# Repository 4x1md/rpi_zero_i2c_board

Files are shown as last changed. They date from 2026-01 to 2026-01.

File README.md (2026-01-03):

# I2C Peripherals Board for Raspberry Pi Zero

The board was developed for communicating some I2C peripherals connected to a Raspberry Pi Zero.

## Schematics

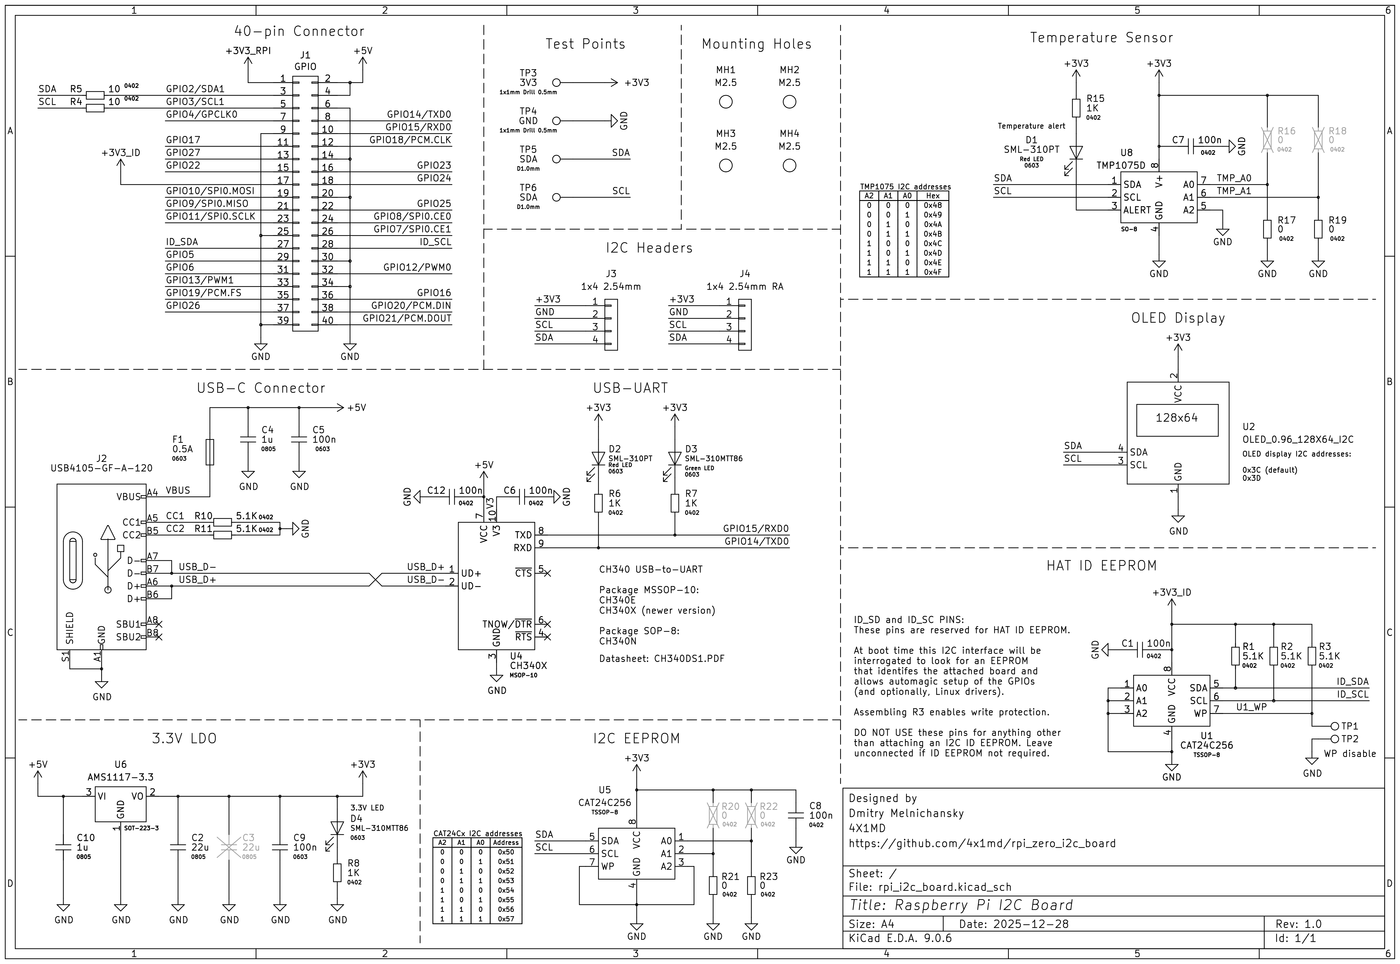
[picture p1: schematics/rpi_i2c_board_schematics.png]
Pi Zero I2C board schematics


## 3D Model

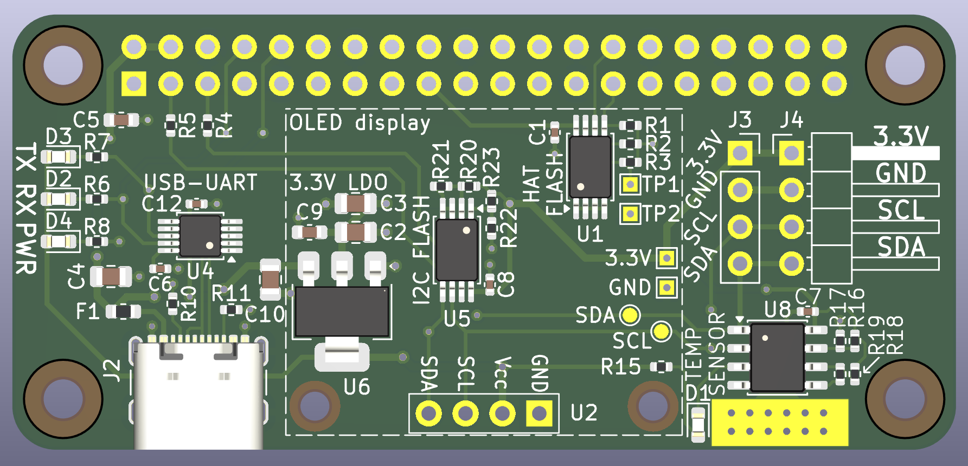
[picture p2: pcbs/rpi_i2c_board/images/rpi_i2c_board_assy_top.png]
Pi Zero I2C board 3D


## Questions? Suggestions?

You are more than welcome to contact me with any questions, suggestions or propositions regarding this project. Please drop an email to ```iosaaris =at= gmail dot com```.

## How to Support or Say Thanks

If you like this project, or found here some useful information and want to say thanks, or encourage me to do more, you can buy me a coffee!



"Buy Me A Coffee" (https://www.buymeacoffee.com/4x1md)

---

73 de 4X1MD

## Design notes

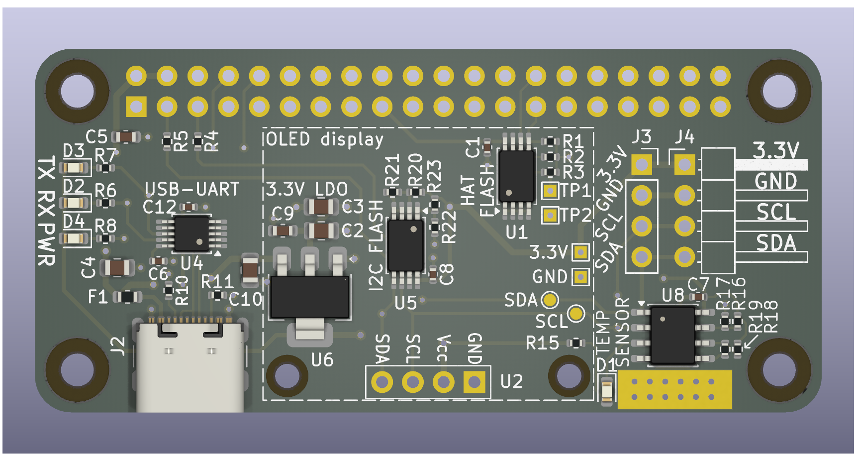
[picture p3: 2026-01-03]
pcbs/rpi_i2c_board/images/rpi_i2c_board_raytracing.png

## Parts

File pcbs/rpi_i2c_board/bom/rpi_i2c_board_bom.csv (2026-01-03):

Reference | Value | Footprint | Qty | FP | LSCS #
C1,C6,C7,C8,C12 | 100n | Capacitor_SMD:C_0402_1005Metric | 5 | 0402 | C1525
C2,C3 | 22u | Capacitor_SMD:C_0805_2012Metric | 2 | 0805 | C45783
C4,C10 | 1u | Capacitor_SMD:C_0805_2012Metric | 2 | 0805 | C28323
C5,C9 | 100n | Capacitor_SMD:C_0603_1608Metric | 2 | 0603 | C14663
D1,D2 | SML-310PT | LED_SMD:LED_0603_1608Metric | 2 | 0603 | C123009
D3,D4 | SML-310MTT86 | LED_SMD:LED_0603_1608Metric | 2 | 0603 | C122984
F1 | 0.5A | Fuse:Fuse_0603_1608Metric | 1 | 0603 | C7472539
J2 | USB4105-GF-A-120 | Connector_USB:USB_C_Receptacle_GCT_USB4105-xx-A_16P_TopMnt_Horizontal | 1 |  | C5184243
R1,R2,R3,R10,R11 | 5.1K | Resistor_SMD:R_0402_1005Metric | 5 | 0402 | C25905
R4,R5 | 10 | Resistor_SMD:R_0402_1005Metric | 2 | 0402 | C25077
R6,R7,R8,R15 | 1K | Resistor_SMD:R_0402_1005Metric | 4 | 0402 | C11702
R16,R17,R18,R19,R20,R21,R22,R23 | 0 | Resistor_SMD:R_0402_1005Metric | 8 | 0402 | C17168
U1,U5 | CAT24C256 | Package_SO:TSSOP-8_4.4x3mm_P0.65mm | 2 | TSSOP-8 | C146734
U4 | CH340X | Package_SO:MSOP-10_3x3mm_P0.5mm | 1 | MSOP-10 | C3035748
U6 | AMS1117-3.3 | Package_TO_SOT_SMD:SOT-223-3_TabPin2 | 1 | SOT-223-3 | C6186
U8 | TMP1075D | Package_SO:SO-8_3.9x4.9mm_P1.27mm | 1 | SO-8 | C2878381

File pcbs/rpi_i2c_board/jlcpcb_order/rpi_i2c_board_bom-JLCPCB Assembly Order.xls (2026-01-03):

JLCPCB BOM Tool - BOM Matching
BOM name：rpi_i2c_board_bom-JLCPCB Assembly Order.xlsx |  |  | Download Time：2025-12-28 21:13:16 |  |  |  | * Our matching results are updated in real-time, but stock and prices may change. If it's been over 24 hours, please re-match before placing your order.
PCB Assembled Qty：5 |  |  | Est. Total Price：18.3235
Your BOM |  |  |  |  | Matched Parts |  |  |  |  |  |  | Order Information
Top Designator | Bottom Designator | Comment | Footprint | JLCPCB Part # | Matches | Part # | Manufacturer | Footprint | Description | Category | Warning | JLCPCB Part # | Product link | Lib Type | Qty | Source | Total Price ($)
C1,C6,C7,C8,C12 |  | 100n | Capacitor_SMD:C_0402_1005Metric |  | Select by System | CL05B104KO5NNNC | Samsung Electro-Mechanics | 0402 | 100nF 16V X7R ±10% 0402 Multilayer Ceramic Capacitors MLCC - SMD/SMT ROHS | Multilayer Ceramic Capacitors MLCC - SMD/SMT |  | C1525 | https://jlcpcb.com/partdetail/1877-CL05B104KO5NNNC/C1525 | Basic | 25 | 25 JLCPCB | 0.03
C2,C3 |  | 22u | Capacitor_SMD:C_0805_2012Metric |  | Select by System | CL21A226MAQNNNE | Samsung Electro-Mechanics | 0805 | 22uF 25V X5R ±20% 0805 Multilayer Ceramic Capacitors MLCC - SMD/SMT ROHS | Multilayer Ceramic Capacitors MLCC - SMD/SMT |  | C45783 | https://jlcpcb.com/partdetail/46786-CL21A226MAQNNNE/C45783 | Basic | 10 | 10 JLCPCB | 0.232
C4,C10 |  | 1u | Capacitor_SMD:C_0805_2012Metric |  | Select by System | CL21B105KBFNNNE | Samsung Electro-Mechanics | 0805 | 1uF 50V X7R ±10% 0805 Multilayer Ceramic Capacitors MLCC - SMD/SMT ROHS | Multilayer Ceramic Capacitors MLCC - SMD/SMT |  | C28323 | https://jlcpcb.com/partdetail/29074-CL21B105KBFNNNE/C28323 | Basic | 10 | 10 JLCPCB | 0.091
C5,C9 |  | 100n | Capacitor_SMD:C_0603_1608Metric |  | Select by System | CC0603KRX7R9BB104 | YAGEO | 0603 | 100nF 50V X7R ±10% 0603 Multilayer Ceramic Capacitors MLCC - SMD/SMT ROHS | Multilayer Ceramic Capacitors MLCC - SMD/SMT |  | C14663 | https://jlcpcb.com/partdetail/YAGEO-CC0603KRX7R9BB104/C14663 | Basic | 10 | 10 JLCPCB | 0.024
D1,D2 |  | SML-310PT | LED_SMD:LED_0603_1608Metric |  | Select by System | SML-310VTT86 | ROHM Semicon | 0603 | 20mA 2V 4mcd 650nm 650nm Red Water Clear 0603 LED Indication - Discrete ROHS | LED Indication - Discrete |  | C123009 | https://jlcpcb.com/partdetail/ROHMSemicon-SML310VTT86/C123009 | Extended | 12 | 12 JLCPCB | 0.8556
D3,D4 |  | SML-310MTT86 | LED_SMD:LED_0603_1608Metric |  | Select by System | SML-310MTT86 | ROHM Semicon | 0603 | 16mcd 2.2V 20mA 570nm 570nm Green Water Clear 0603 LED Indication - Discrete ROHS | LED Indication - Discrete |  | C122984 | https://jlcpcb.com/partdetail/ROHMSemicon-SML310MTT86/C122984 | Extended | 14 | 14 JLCPCB | 1.19
F1 |  | 0.5A | Fuse:Fuse_0603_1608Metric |  | Select by System | 0603L050/16AR | LUTE | 0603 | -40℃~+85℃ 1.05mm 1.15mm 1.85mm 100ms 100mΩ 16V 1A 40A 500mA 500mW 800mΩ 0603 Resettable Fuses ROHS | Resettable Fuses |  | C7472539 | https://jlcpcb.com/partdetail/LUTE-0603L05016AR/C7472539 | Extended | 9 | 9 JLCPCB | 0.4959
J2 |  | USB4105-GF-A-120 | Connector_USB:USB_C_Receptacle_GCT_USB4105-xx-A_16P_TopMnt_Horizontal |  | Select by System | USB4105-GF-A-120 | Global Connector Technology | SMD | -40℃~+85℃ 1 16P 48V 5A Black Female Type-C USB2.0 SMD USB Connectors ROHS | USB Connectors |  | C5184243 | https://jlcpcb.com/partdetail/5849584-USB4105_GF_A120/C5184243 | Extended | 5 | 5 JLCPCB | 5.661
R1,R2,R3,R10,R11 |  | 5.1K | Resistor_SMD:R_0402_1005Metric |  | Select by System | 0402WGF5101TCE | UNI-ROYAL(Uniroyal Elec) | 0402 | -55℃~+155℃ 5.1kΩ 50V 62.5mW Thick Film Resistor ±1% ±100ppm/℃ 0402 Chip Resistor - Surface Mount ROHS | Chip Resistor - Surface Mount |  | C25905 | https://jlcpcb.com/partdetail/26648-0402WGF5101TCE/C25905 | Basic | 25 | 25 JLCPCB | 0.0125
R4,R5 |  | 10 | Resistor_SMD:R_0402_1005Metric |  | Select by System | 0402WGF100JTCE | UNI-ROYAL(Uniroyal Elec) | 0402 | -55℃~+155℃ 10Ω 50V 62.5mW Thick Film Resistor ±1% ±200ppm/℃ 0402 Chip Resistor - Surface Mount ROHS | Chip Resistor - Surface Mount |  | C25077 | https://jlcpcb.com/partdetail/25820-0402WGF100JTCE/C25077 | Basic | 10 | 10 JLCPCB | 0.006
R6,R7,R8,R15 |  | 1K | Resistor_SMD:R_0402_1005Metric |  | Select by System | 0402WGF1001TCE | UNI-ROYAL(Uniroyal Elec) | 0402 | -55℃~+155℃ 1kΩ 50V 62.5mW Thick Film Resistor ±1% ±100ppm/℃ 0402 Chip Resistor - Surface Mount ROHS | Chip Resistor - Surface Mount |  | C11702 | https://jlcpcb.com/partdetail/12256-0402WGF1001TCE/C11702 | Basic | 20 | 20 JLCPCB | 0.012
R16,R17,R18,R19,R20,R21,R22,R23 |  | 0 | Resistor_SMD:R_0402_1005Metric |  | Select by System | 0402WGF0000TCE | UNI-ROYAL(Uniroyal Elec) | 0402 | -55℃~+155℃ 0Ω 50V 62.5mW Thick Film Resistor ±1% ±800ppm/℃ 0402 Chip Resistor - Surface Mount ROHS | Chip Resistor - Surface Mount |  | C17168 | https://jlcpcb.com/partdetail/17853-0402WGF0000TCE/C17168 | Basic | 40 | 40 JLCPCB | 0.02
U1,U5 |  | CAT24C256 | Package_SO:TSSOP-8_4.4x3mm_P0.65mm |  | Select by System | CAT24C256YI-GT3 | onsemi | TSSOP-8 | -40℃~+85℃ 1,000,000 cycles 1.8V~5.5V 100 Years 1MHz 256Kbit 5ms I2C TSSOP-8 EEPROM ROHS | EEPROM |  | C146734 | https://jlcpcb.com/partdetail/onsemi-CAT24C256YIGT3/C146734 | Extended | 10 | 10 JLCPCB | 3.987
U4 |  | CH340X | Package_SO:MSOP-10_3x3mm_P0.5mm |  | Select by System | CH340X | WCH(Jiangsu Qin Heng) | MSOP-10 | -20℃~+70℃ 2Mbps 3.3V USB 2.0 USB to serial MSOP-10 USB Converters ROHS | USB Converters |  | C3035748 | https://jlcpcb.com/partdetail/WCH_Jiangsu_Qin_Heng-CH340X/C3035748 | Extended | 5 | 5 JLCPCB | 3.097
U6 |  | AMS1117-3.3 | Package_TO_SOT_SMD:SOT-223-3_TabPin2 |  | Select by System | AMS1117-3.3 | Advanced Monolithic Systems | SOT-223 | -40℃~+125℃ 0.003%Vout 1 1.1V@(800mA) 16V 1A 3.3V 5mA 72dB@(120Hz) Fixed Over Current Protection Positive SOT-223 Voltage Regulators - Linear, Low Drop Out (LDO) Regulators ROHS | Voltage Regulators - Linear, Low Drop Out (LDO) Regulators |  | C6186 | https://jlcpcb.com/partdetail/Advanced_MonolithicSystems-AMS1117_33/C6186 | Basic | 5 | 5 JLCPCB | 0.806
U8 |  | TMP1075D | Package_SO:SO-8_3.9x4.9mm_P1.27mm |  | Select by System | TMP1075DR | Texas Instruments | SOIC-8 | -55℃~+125℃ 1.7V~5.5V 12bit 3.5uA 7ms I2C ±1℃ SOIC-8 Temperature Sensors ROHS | Temperature Sensors |  | C2878381 | https://jlcpcb.com/partdetail/TexasInstruments-TMP1075DR/C2878381 | Extended | 5 | 5 JLCPCB | 1.8035

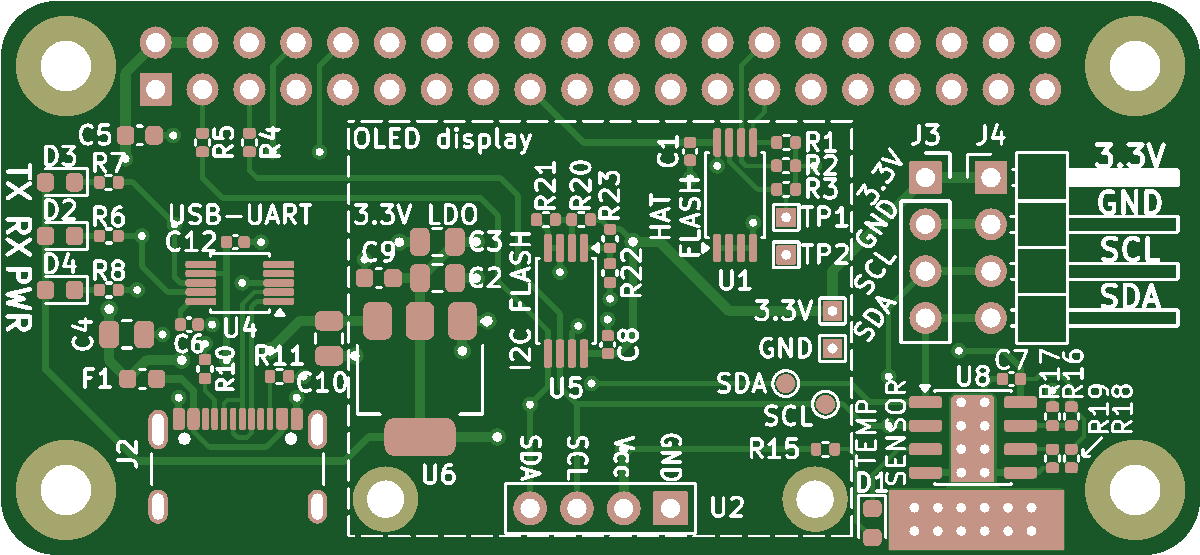
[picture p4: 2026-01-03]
pcbs/rpi_i2c_board/jlcpcb_order/rpi_i2c_board_jlcpcb_top.png

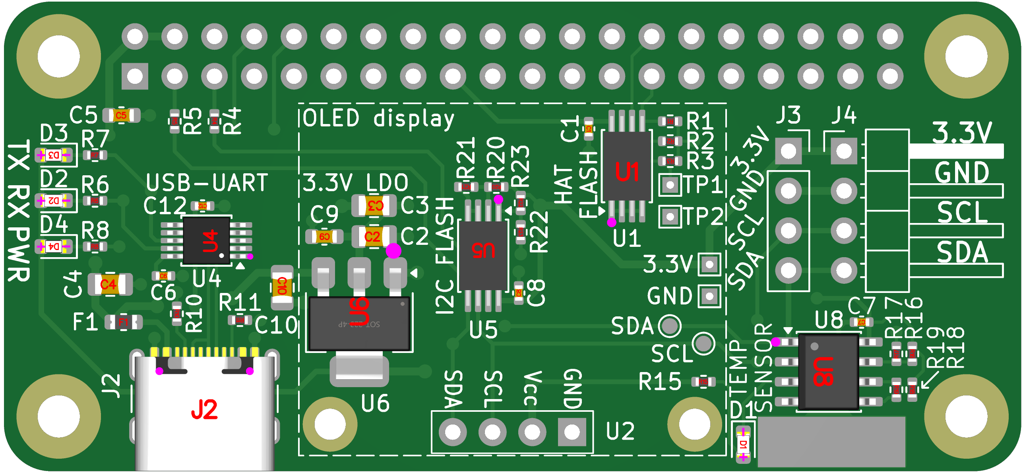
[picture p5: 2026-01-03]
pcbs/rpi_i2c_board/jlcpcb_order/rpi_i2c_board_jlcpcb_placement.png

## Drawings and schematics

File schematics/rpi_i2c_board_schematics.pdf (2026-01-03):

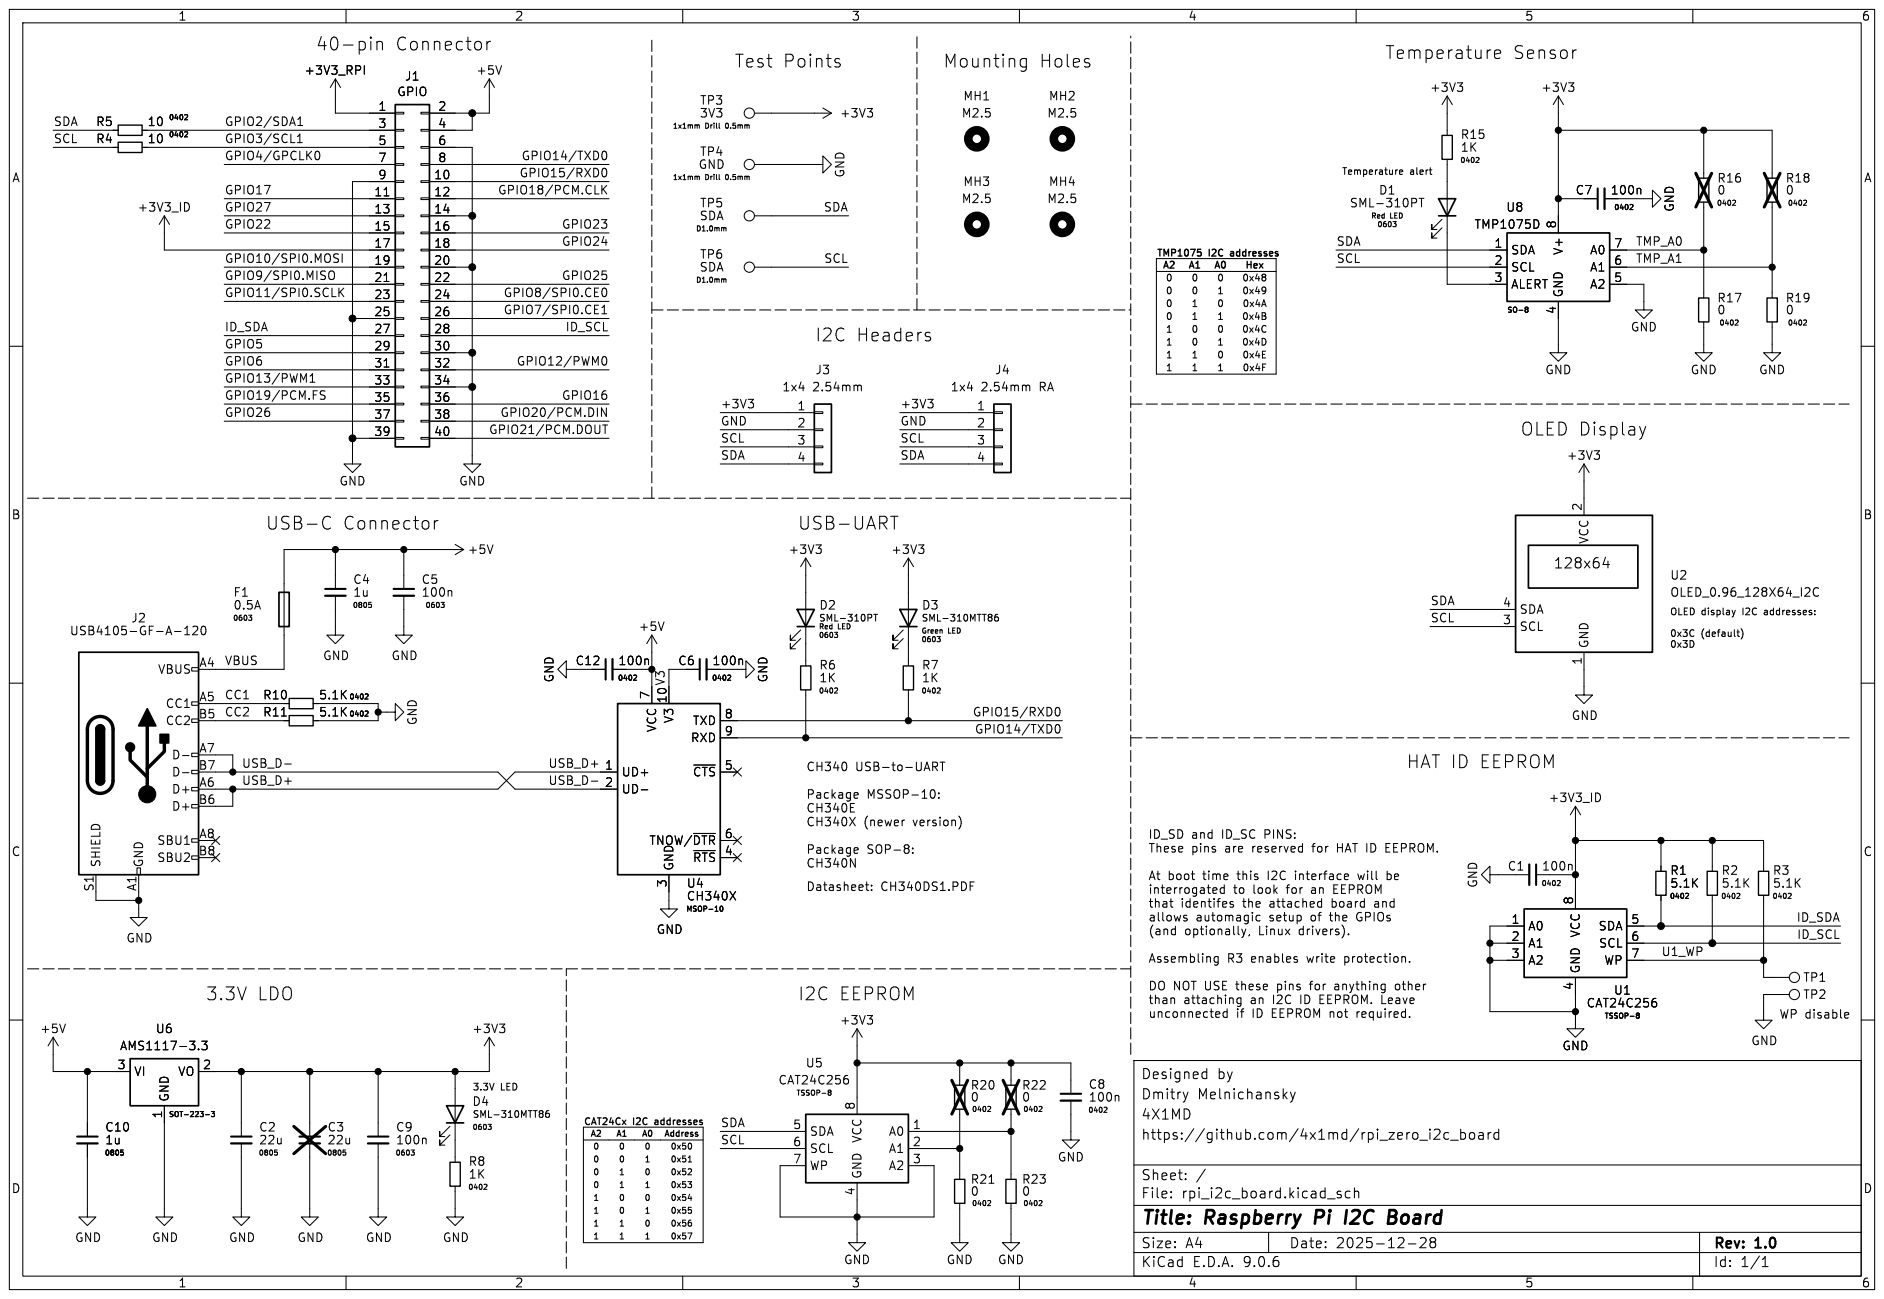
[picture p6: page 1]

+3V3 GPIO18/PCM.CLK GPIO15/RXD0 GPIO6 GPIO5 GPIO19/PCM.FS GPIO26 GPIO13/PWM1 GPIO9/SPI0.MISO

3 TXD 8 RXD 9 ~{CTS}5 TNOW/~{DTR}6 ~{RTS}4 U4 CH340X

3 TXD 8 RXD 9 ~{CTS}5 TNOW/~{DTR}6 ~{RTS}4

Package MSSOP-10: CH340E CH340X (newer version)

File: rpi_i2c_board.kicad_sch Sheet: / https://github.com/4x1md/rpi_zero_i2c_board

Id: 1/1 Title: Raspberry Pi I2C Board

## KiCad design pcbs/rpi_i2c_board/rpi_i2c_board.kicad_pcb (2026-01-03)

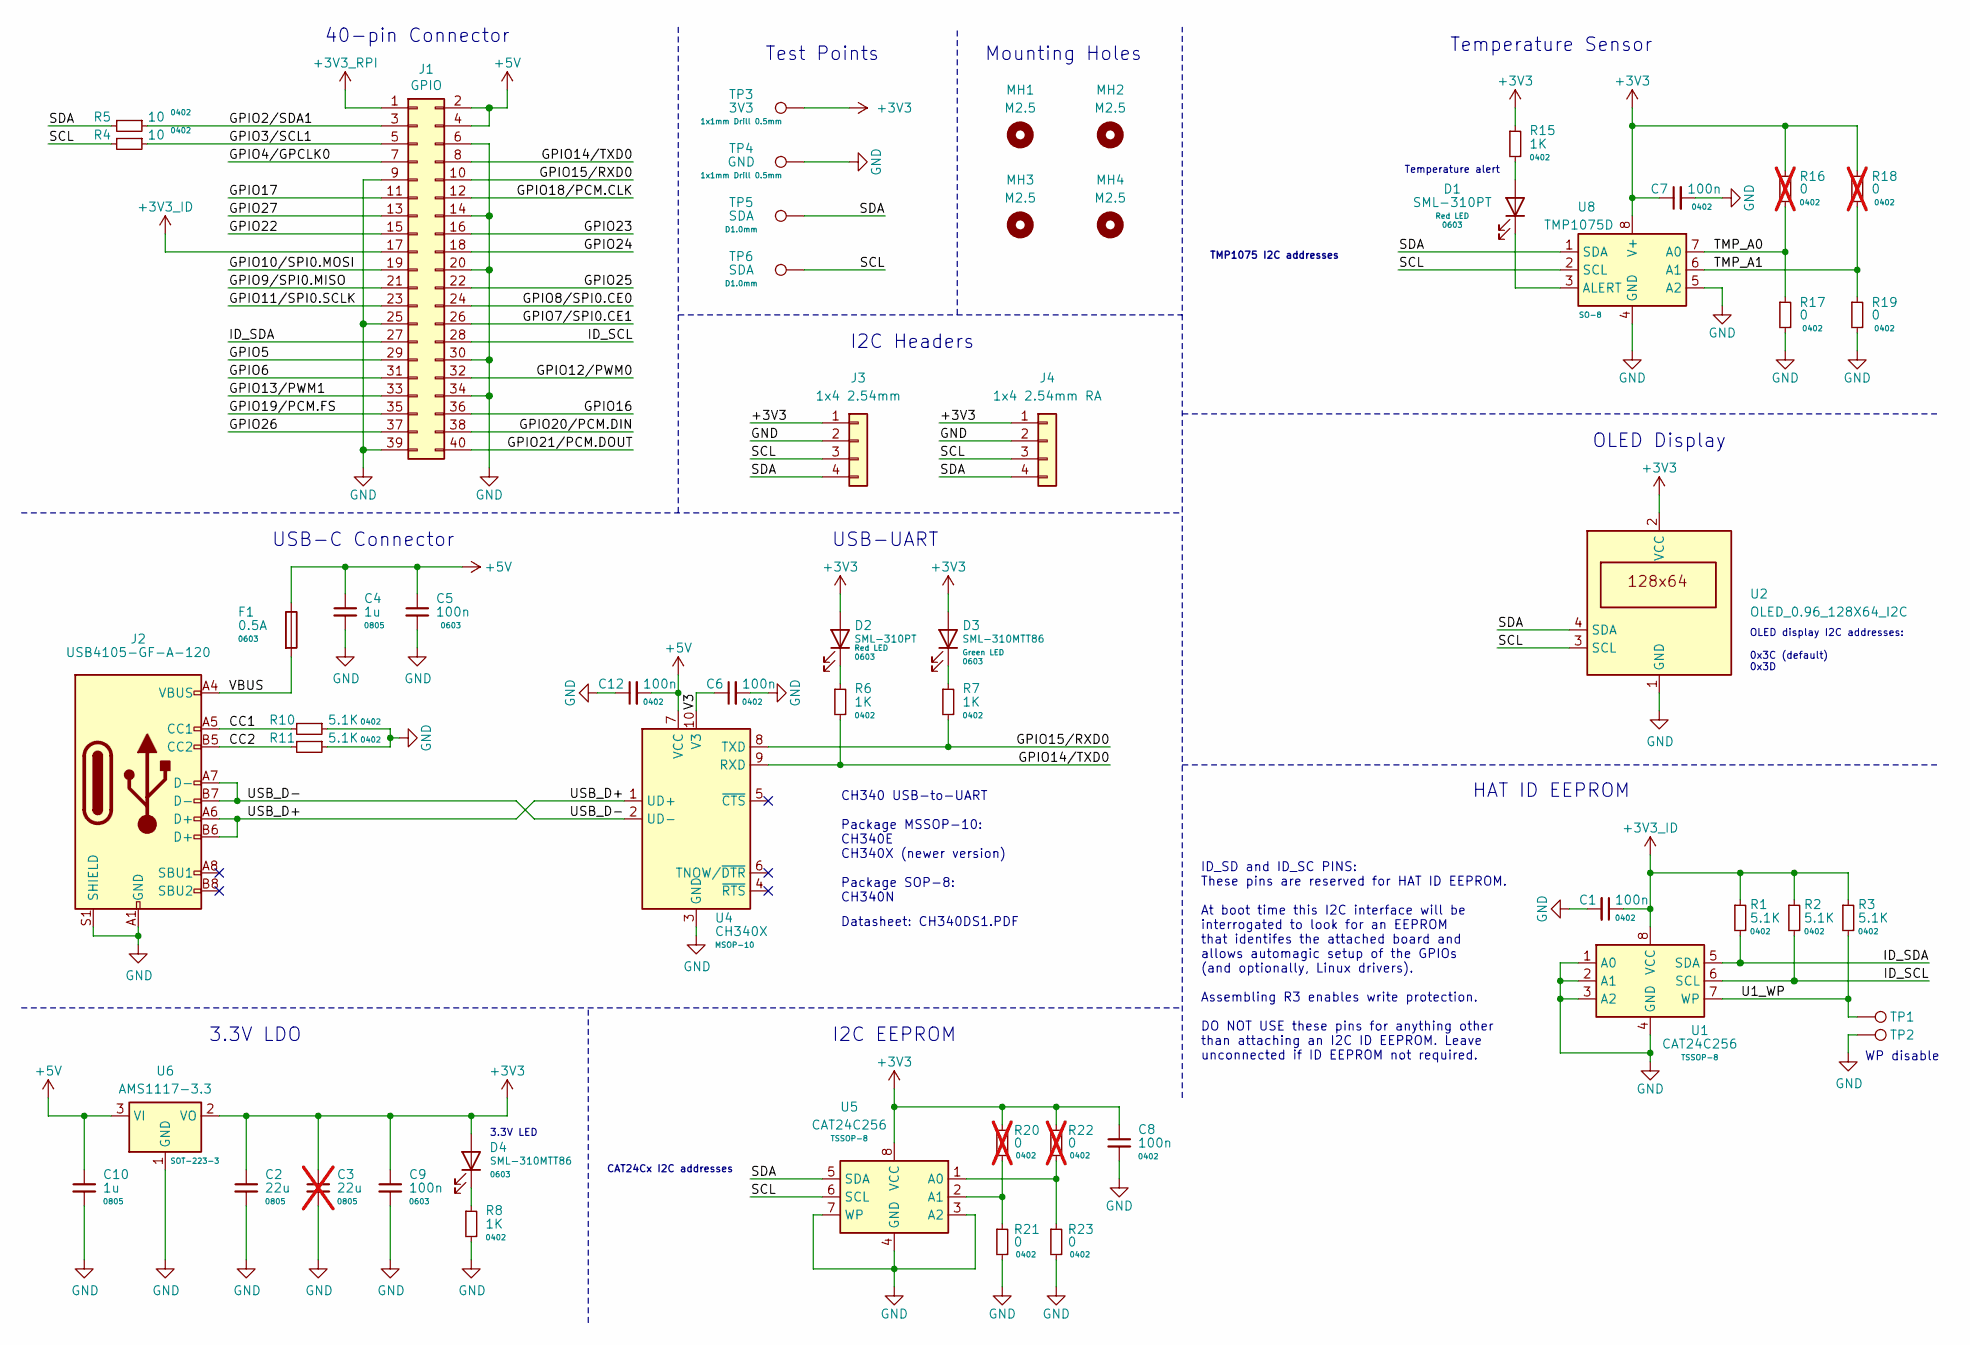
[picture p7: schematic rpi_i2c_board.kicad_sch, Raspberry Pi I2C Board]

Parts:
C1, C6, C7, C8, C12: 100n; C_0402_1005Metric
C2: 22u; C_0805_2012Metric
C3: 22u; C_0805_2012Metric; not fitted
C4, C10: 1u; C_0805_2012Metric
C5, C9: 100n; C_0603_1608Metric
D1, D2: SML-310PT; LED_0603_1608Metric
D3, D4: SML-310MTT86; LED_0603_1608Metric
F1: 0.5A; Fuse_0603_1608Metric
J1: GPIO; PinSocket_2x20_P2.54mm_Vertical
J2: USB4105-GF-A-120; USB_C_Receptacle_GCT_USB4105-xx-A_16P_TopMnt_Horizontal
J3: 1x4 2.54mm; PinSocket_1x04_P2.54mm_Vertical
J4: 1x4 2.54mm RA; PinHeader_1x04_P2.54mm_Horizontal
MH1, MH2, MH3, MH4: M2.5; MountingHole_2.7mm_M2.5_SolderMaskOpening
R1, R2, R3, R10, R11: 5.1K; R_0402_1005Metric
R4, R5: 10; R_0402_1005Metric
R6, R7, R8, R15: 1K; R_0402_1005Metric
R16, R18, R20, R22: 0; R_0402_1005Metric; not fitted
R17, R19, R21, R23: 0; R_0402_1005Metric
TP1: ID SDA; TestPoint_THTPad_1.0x1.0mm_Drill0.5mm
TP2: ID SCL; TestPoint_THTPad_1.0x1.0mm_Drill0.5mm
TP3: 3V3; TestPoint_THTPad_1.0x1.0mm_Drill0.5mm
TP4: GND; TestPoint_THTPad_1.0x1.0mm_Drill0.5mm
TP5, TP6: SDA; TestPoint_Pad_D1.0mm
U1, U5: CAT24C256; TSSOP-8_4.4x3mm_P0.65mm
U2: OLED_0.96_128X64_I2C; OLED_0.96_128X64_I2C_2MH
U4: CH340X; MSOP-10_3x3mm_P0.5mm
U6: AMS1117-3.3; SOT-223-3_TabPin2
U8: TMP1075D; SO-8_3.9x4.9mm_P1.27mm

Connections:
+3V3: C2.1, C3.1, C7.1, C8.1, C9.1, D2.2 (A), D3.2 (A), D4.2 (A), J3.1, J4.1, R15.1, R16.1, R18.1, R20.1, R22.1, TP3.1, U2.2 (VCC), U5.8 (VCC), U6.2 (VO), U8.8 (V+)
+3V3_ID: C1.1, J1.17, R1.1, R2.1, R3.1, U1.8 (VCC)
+3V3_RPI: J1.1
+5V: C4.1, C5.1, C10.1, C12.2, F1.1, J1.2, J1.4, U4.7 (VCC), U6.3 (VI)
/CC1: J2.A5 (CC1), R10.2
/CC2: J2.B5 (CC2), R11.2
/GPIO2/SDA1: J1.3, R5.1
/GPIO3/SCL1: J1.5, R4.1
/GPIO4/GPCLK0: J1.7
/GPIO5: J1.29
/GPIO6: J1.31
/GPIO7/SPI0.CE1: J1.26
/GPIO8/SPI0.CE0: J1.24
/GPIO9/SPI0.MISO: J1.21
/GPIO10/SPI0.MOSI: J1.19
/GPIO11/SPI0.SCLK: J1.23
/GPIO12/PWM0: J1.32
/GPIO13/PWM1: J1.33
/GPIO14/TXD0: J1.8, R6.2, U4.9 (RXD)
/GPIO15/RXD0: J1.10, R7.2, U4.8 (TXD)
/GPIO16: J1.36
/GPIO17: J1.11
/GPIO18/PCM.CLK: J1.12
/GPIO19/PCM.FS: J1.35
/GPIO20/PCM.DIN: J1.38
/GPIO21/PCM.DOUT: J1.40
/GPIO22: J1.15
/GPIO23: J1.16
/GPIO24: J1.18
/GPIO25: J1.22
/GPIO26: J1.37
/GPIO27: J1.13
/ID_SCL: J1.28, R2.2, U1.6 (SCL)
/ID_SDA: J1.27, R1.2, U1.5 (SDA)
/SCL: J3.3, J4.3, R4.2, TP6.1, U2.3 (SCL), U5.6 (SCL), U8.2 (SCL)
/SDA: J3.4, J4.4, R5.2, TP5.1, U2.4 (SDA), U5.5 (SDA), U8.1 (SDA)
/TMP_A0: R16.2, R17.1, U8.7 (A0)
/TMP_A1: R18.2, R19.1, U8.6 (A1)
/U1_WP: R3.2, TP1.1, U1.7 (WP)
/USB_D+: J2.A6 (D+), J2.B6 (D+), U4.1 (UD+)
/USB_D-: J2.A7 (D-), J2.B7 (D-), U4.2 (UD-)
/V3: C6.1, U4.10 (V3)
/VBUS: F1.2, J2.A4 (VBUS), J2.A9 (VBUS), J2.B4 (VBUS), J2.B9 (VBUS)
GND: C1.2, C2.2, C3.2, C4.2, C5.2, C6.2, C7.2, C8.2, C9.2, C10.2, C12.1, J1.6, J1.9, J1.14, J1.20, J1.25, J1.30, J1.34, J1.39, J2.A1 (GND), J2.A12 (GND), J2.B1 (GND), J2.B12 (GND), J2.S1 (SHIELD), J3.2, J4.2, R8.2, R10.1, R11.1, R17.2, R19.2, R21.2, R23.2, TP2.1, TP4.1, U1.1 (A0), U1.2 (A1), U1.3 (A2), U1.4 (GND), U2.1 (GND), U4.3 (GND), U5.3 (A2), U5.4 (GND), U5.7 (WP), U6.1 (GND), U8.4 (GND), U8.5 (A2)
unnamed: D1.2 (A), R15.2
unnamed: D1.1 (K), U8.3 (ALERT)
unnamed: D2.1 (K), R6.1
unnamed: D3.1 (K), R7.1
unnamed: D4.1 (K), R8.1
unnamed: R22.2, R23.1, U5.1 (A0)
unnamed: R20.2, R21.1, U5.2 (A1)

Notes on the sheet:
OLED Display
USB-C Connector
Mounting Holes
3.3V LED
Test Points
3.3V LDO
USB-UART
I2C EEPROM
WP disable
ID_SD and ID_SC PINS: These pins are reserved for HAT ID EEPROM. At boot time this I2C interface will be interrogated to look for an EEPROM that identifes the attached board and allows automagic setup of the GPIOs (and optionally, Linux drivers). Assembling R3 enables write protection. DO NOT USE t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
CH340 USB-to-UART Package MSSOP-10: CH340E CH340X (newer version) Package SOP-8: CH340N
Datasheet: CH340DS1.PDF
40-pin Connector
OLED display I2C addresses: 0x3C (default) 0x3D
TMP1075 I2C addresses
CAT24Cx I2C addresses
Temperature Sensor
HAT ID EEPROM
Temperature alert
I2C Headers

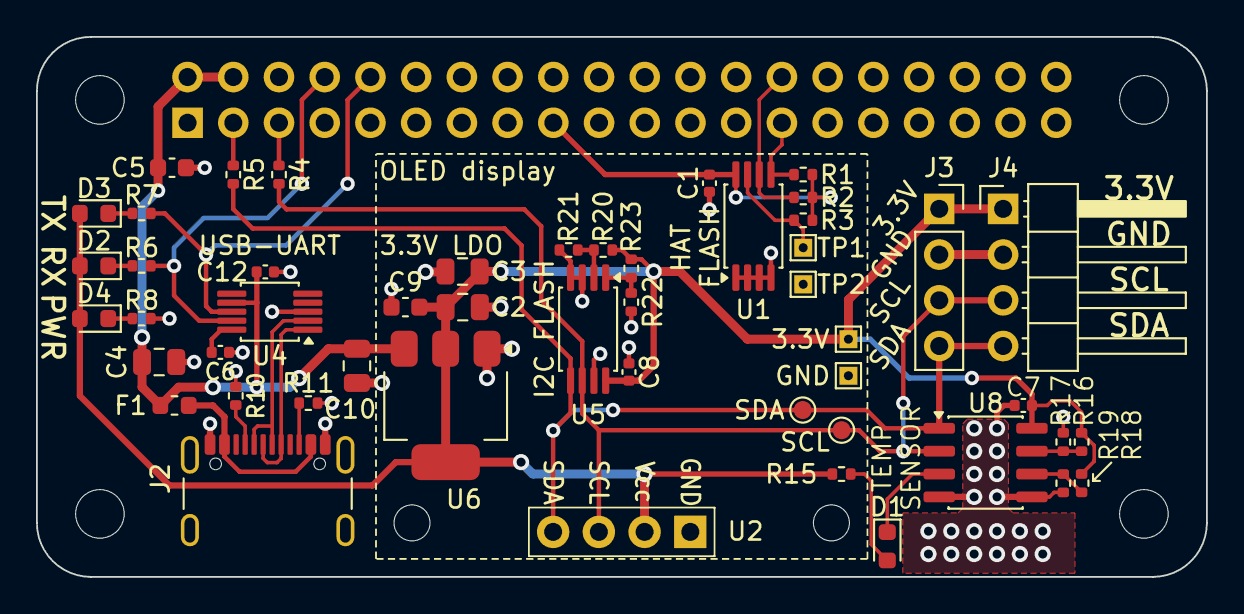
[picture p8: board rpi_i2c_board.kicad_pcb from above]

Board: 2 copper layers, 65.0 x 30.0 mm, 55 parts (1 on the bottom side), 28 nets.

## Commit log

2025-12-29 Project schematics
2026-01-03 KiCAD project and PCB order files.
    [rpi_i2c_board-B_Cu.gbl, rpi_i2c_board-B_Mask.gbs, rpi_i2c_board-B_Silkscreen.gbo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]
